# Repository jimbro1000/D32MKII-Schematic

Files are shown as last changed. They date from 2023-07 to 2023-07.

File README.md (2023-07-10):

# Dragon 32 MKII Schematic

Captured in KiCad by Stewart Orchard 2015-2019

Original design by Dragon Data Ltd circa 1982

PCB Reproduction by Julian Brown 2023

## Why?

The published Dragon schematics do not appear to include MKII versions, which can be a problem for repairs as there are differences in the memory configuration, the video circuit and logic gate pin numbers. I captured this information around the year 1998 with reference to the existing ISS2 schematics, a multimeter and a real MKII ISS6 main board, and have finally got round to recording it as a KiCad project.

## Disclaimer

Much as I would like to think that I've got this 100% correct, there is always the chance that there are mistakes and omissions. I would recommend checking that the information is accurate before using this schematic for anything potentially expensive.

## PCB Design

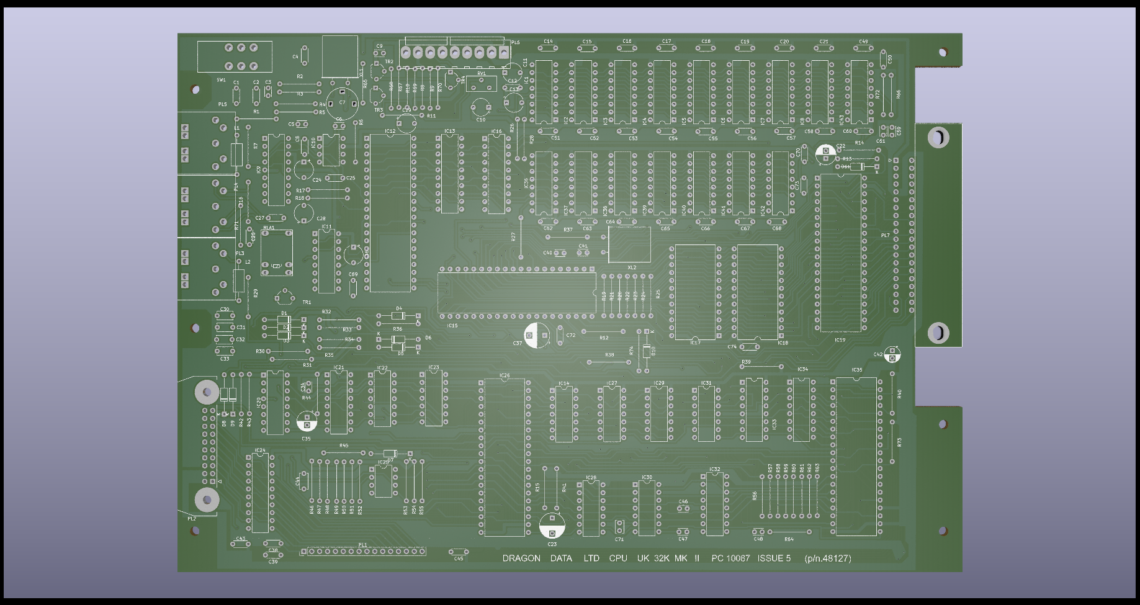
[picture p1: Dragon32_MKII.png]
render of pcb


The PCB layout has been added to further assist with rapid identification of components and 
interconnections between components

This is not an attempt to reverse-engineer the board for production and no support will be given

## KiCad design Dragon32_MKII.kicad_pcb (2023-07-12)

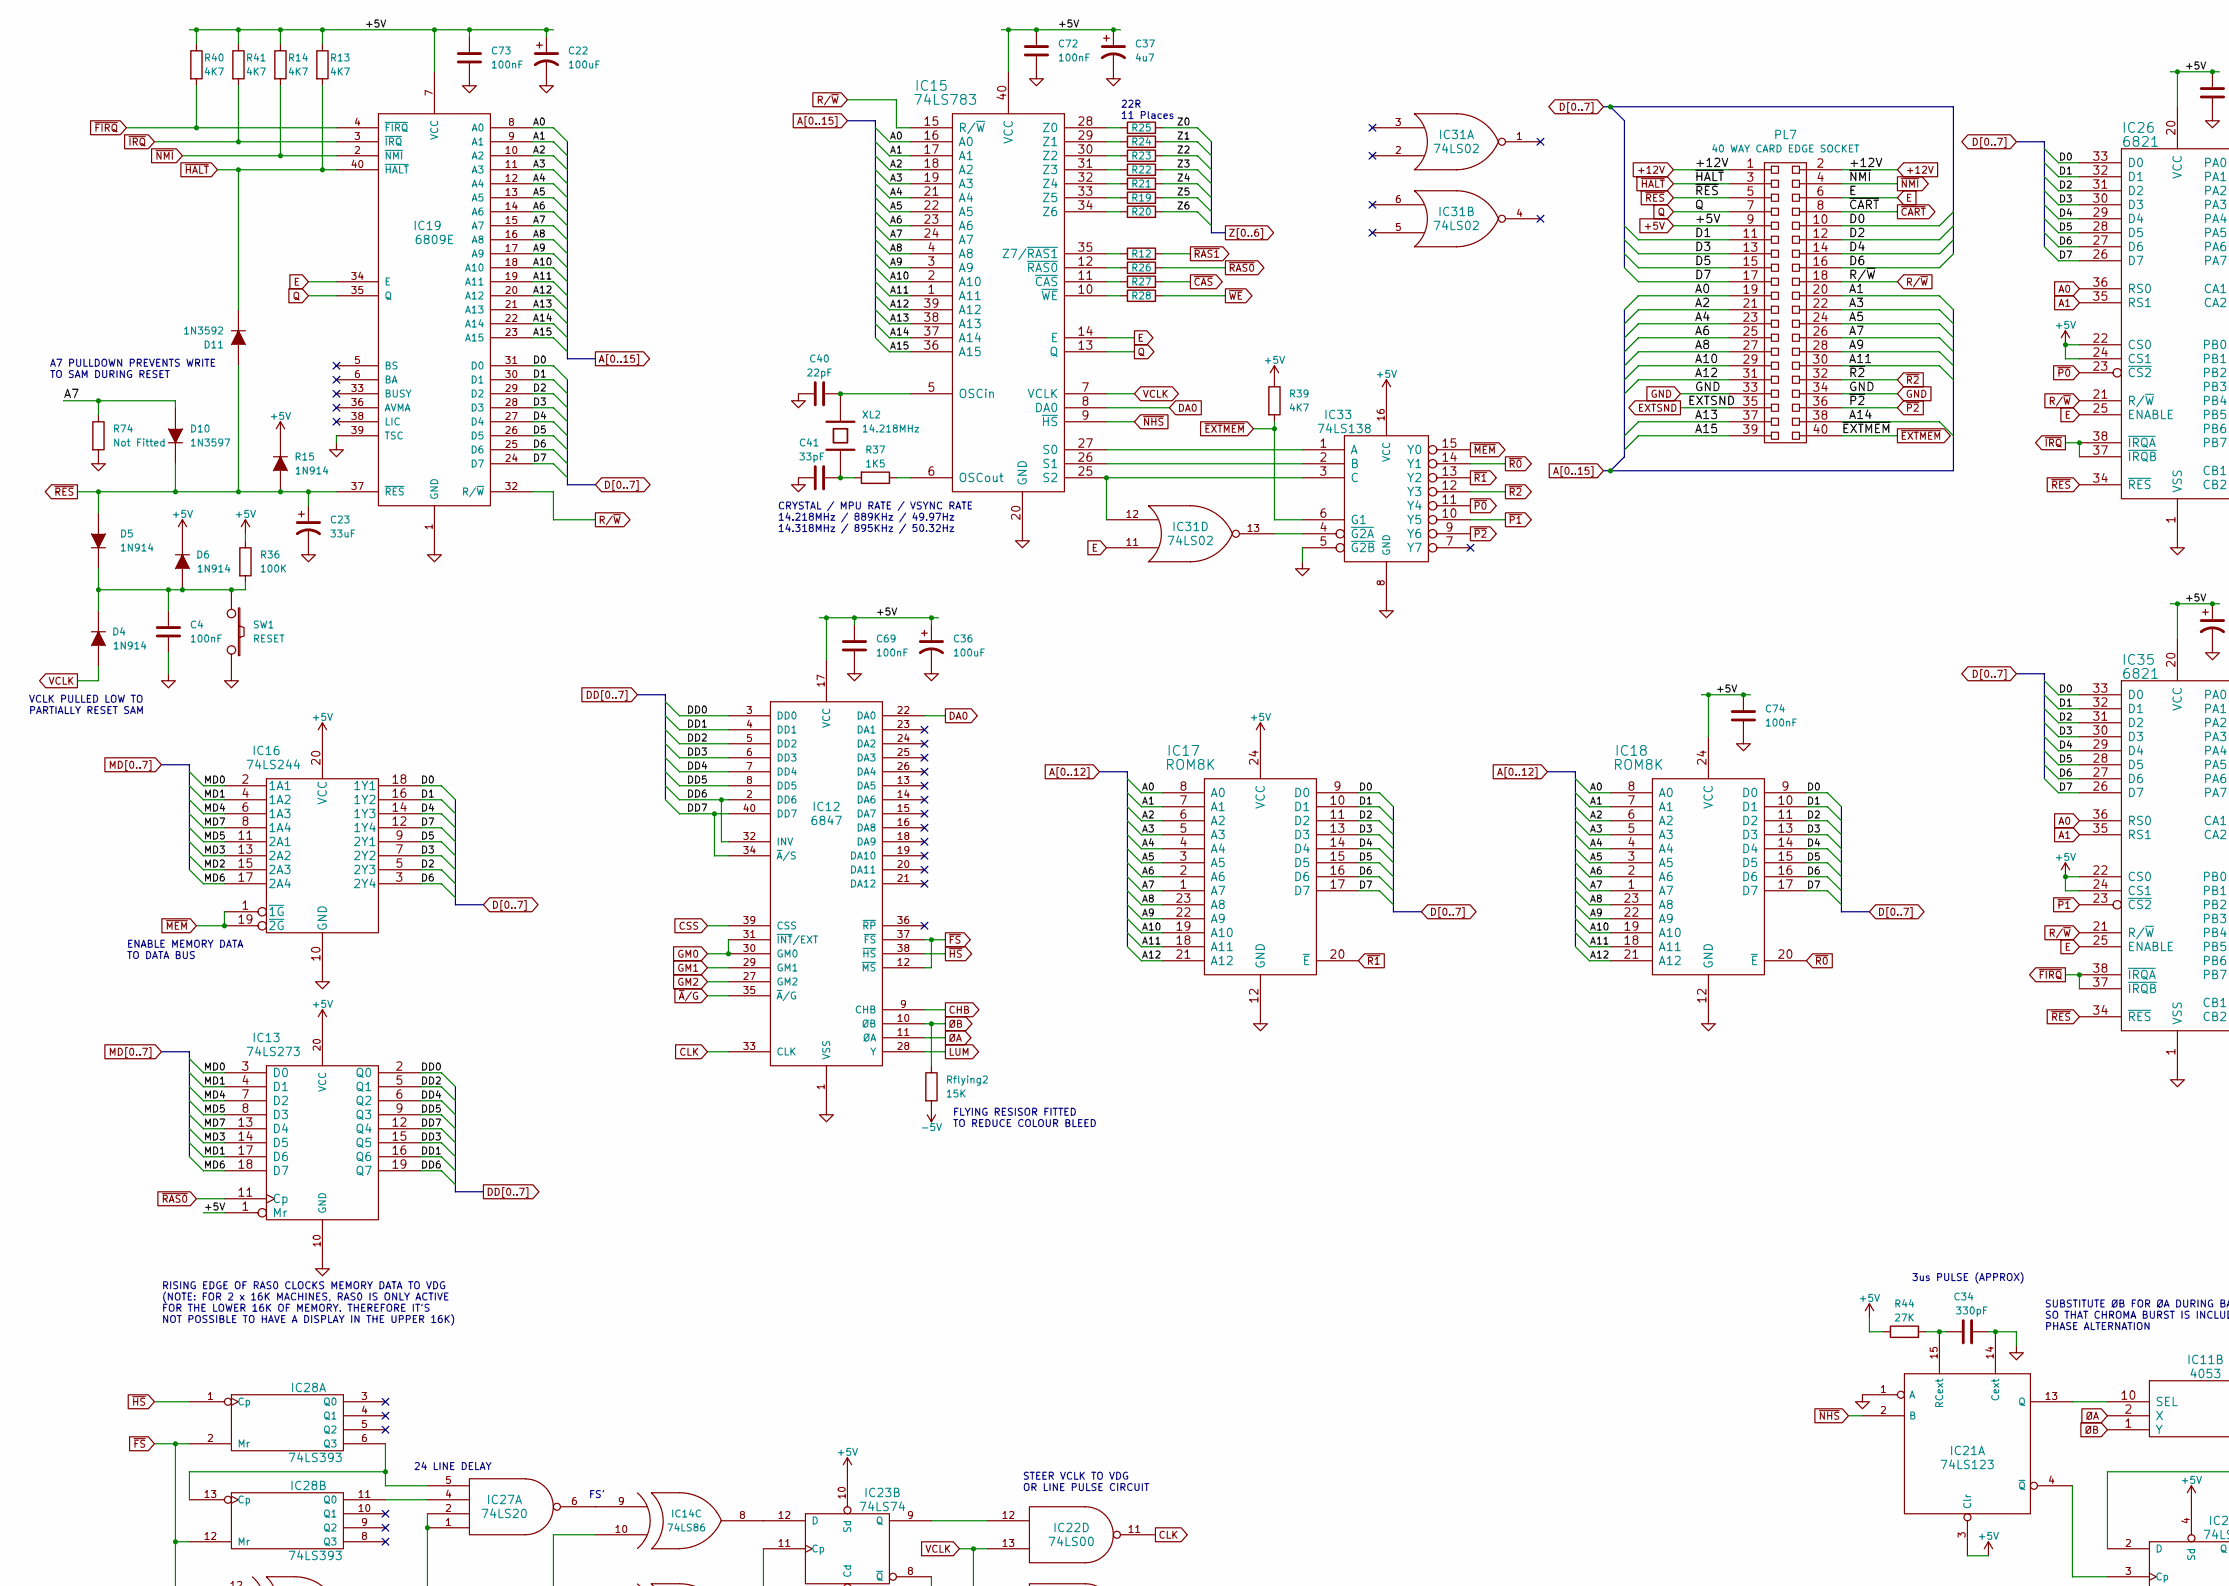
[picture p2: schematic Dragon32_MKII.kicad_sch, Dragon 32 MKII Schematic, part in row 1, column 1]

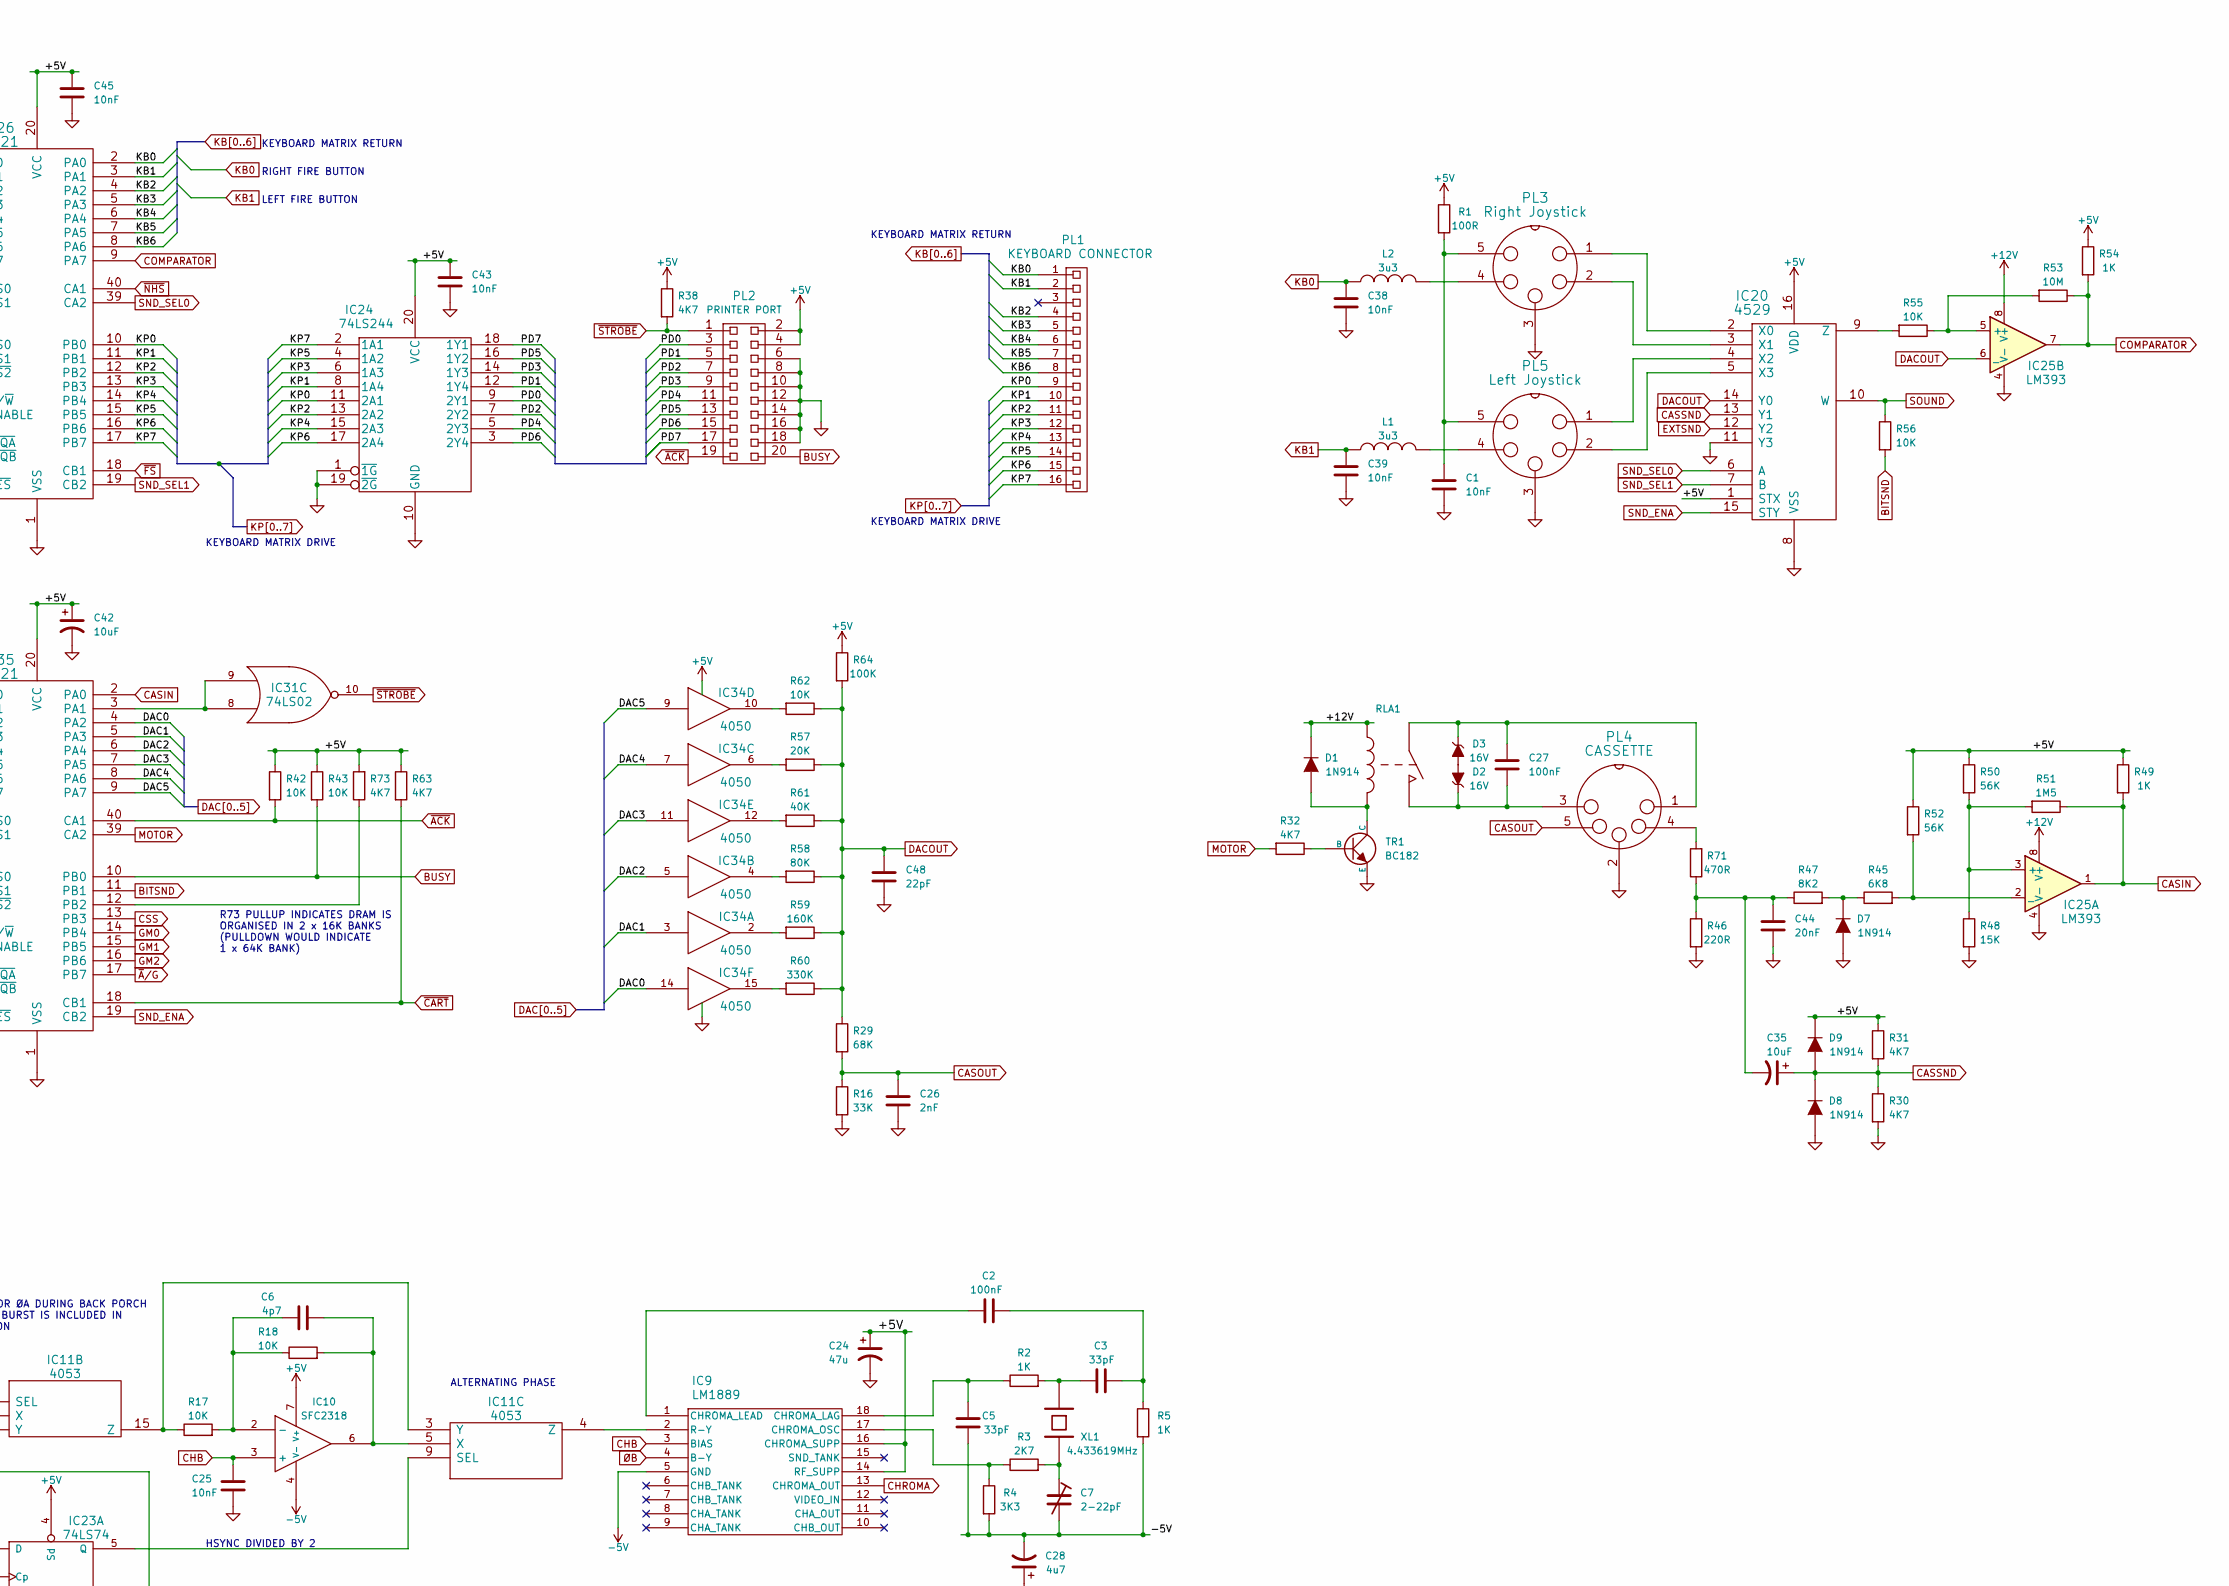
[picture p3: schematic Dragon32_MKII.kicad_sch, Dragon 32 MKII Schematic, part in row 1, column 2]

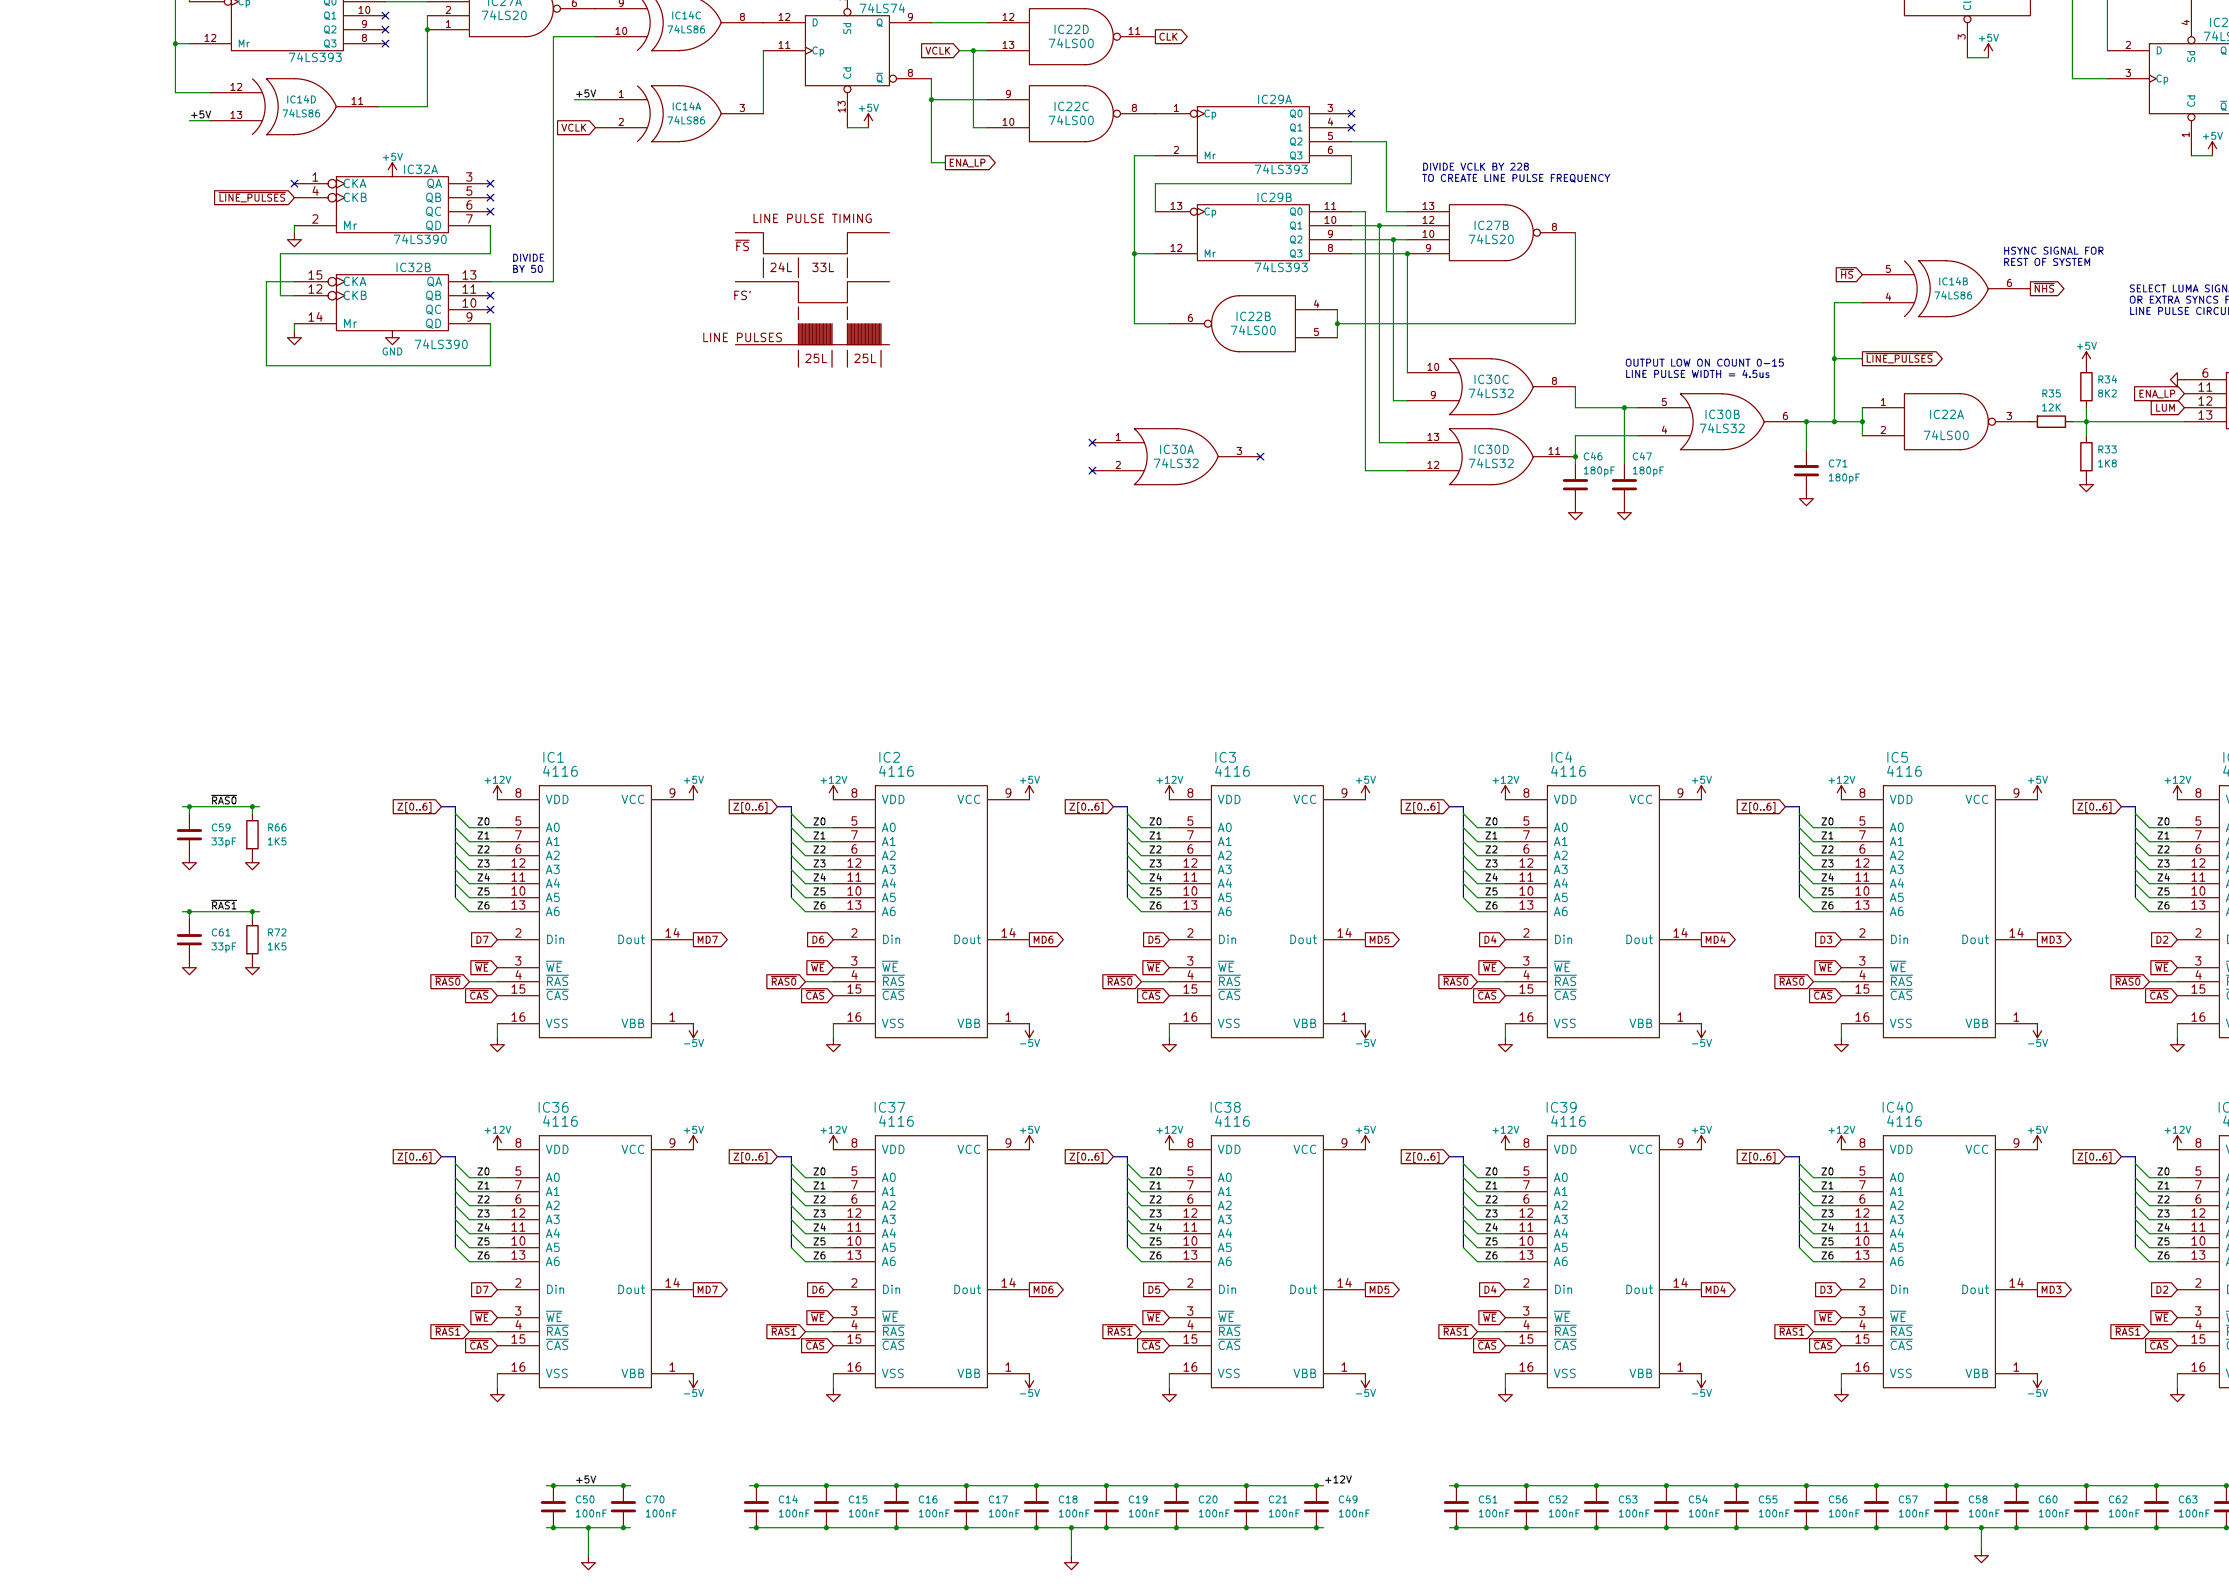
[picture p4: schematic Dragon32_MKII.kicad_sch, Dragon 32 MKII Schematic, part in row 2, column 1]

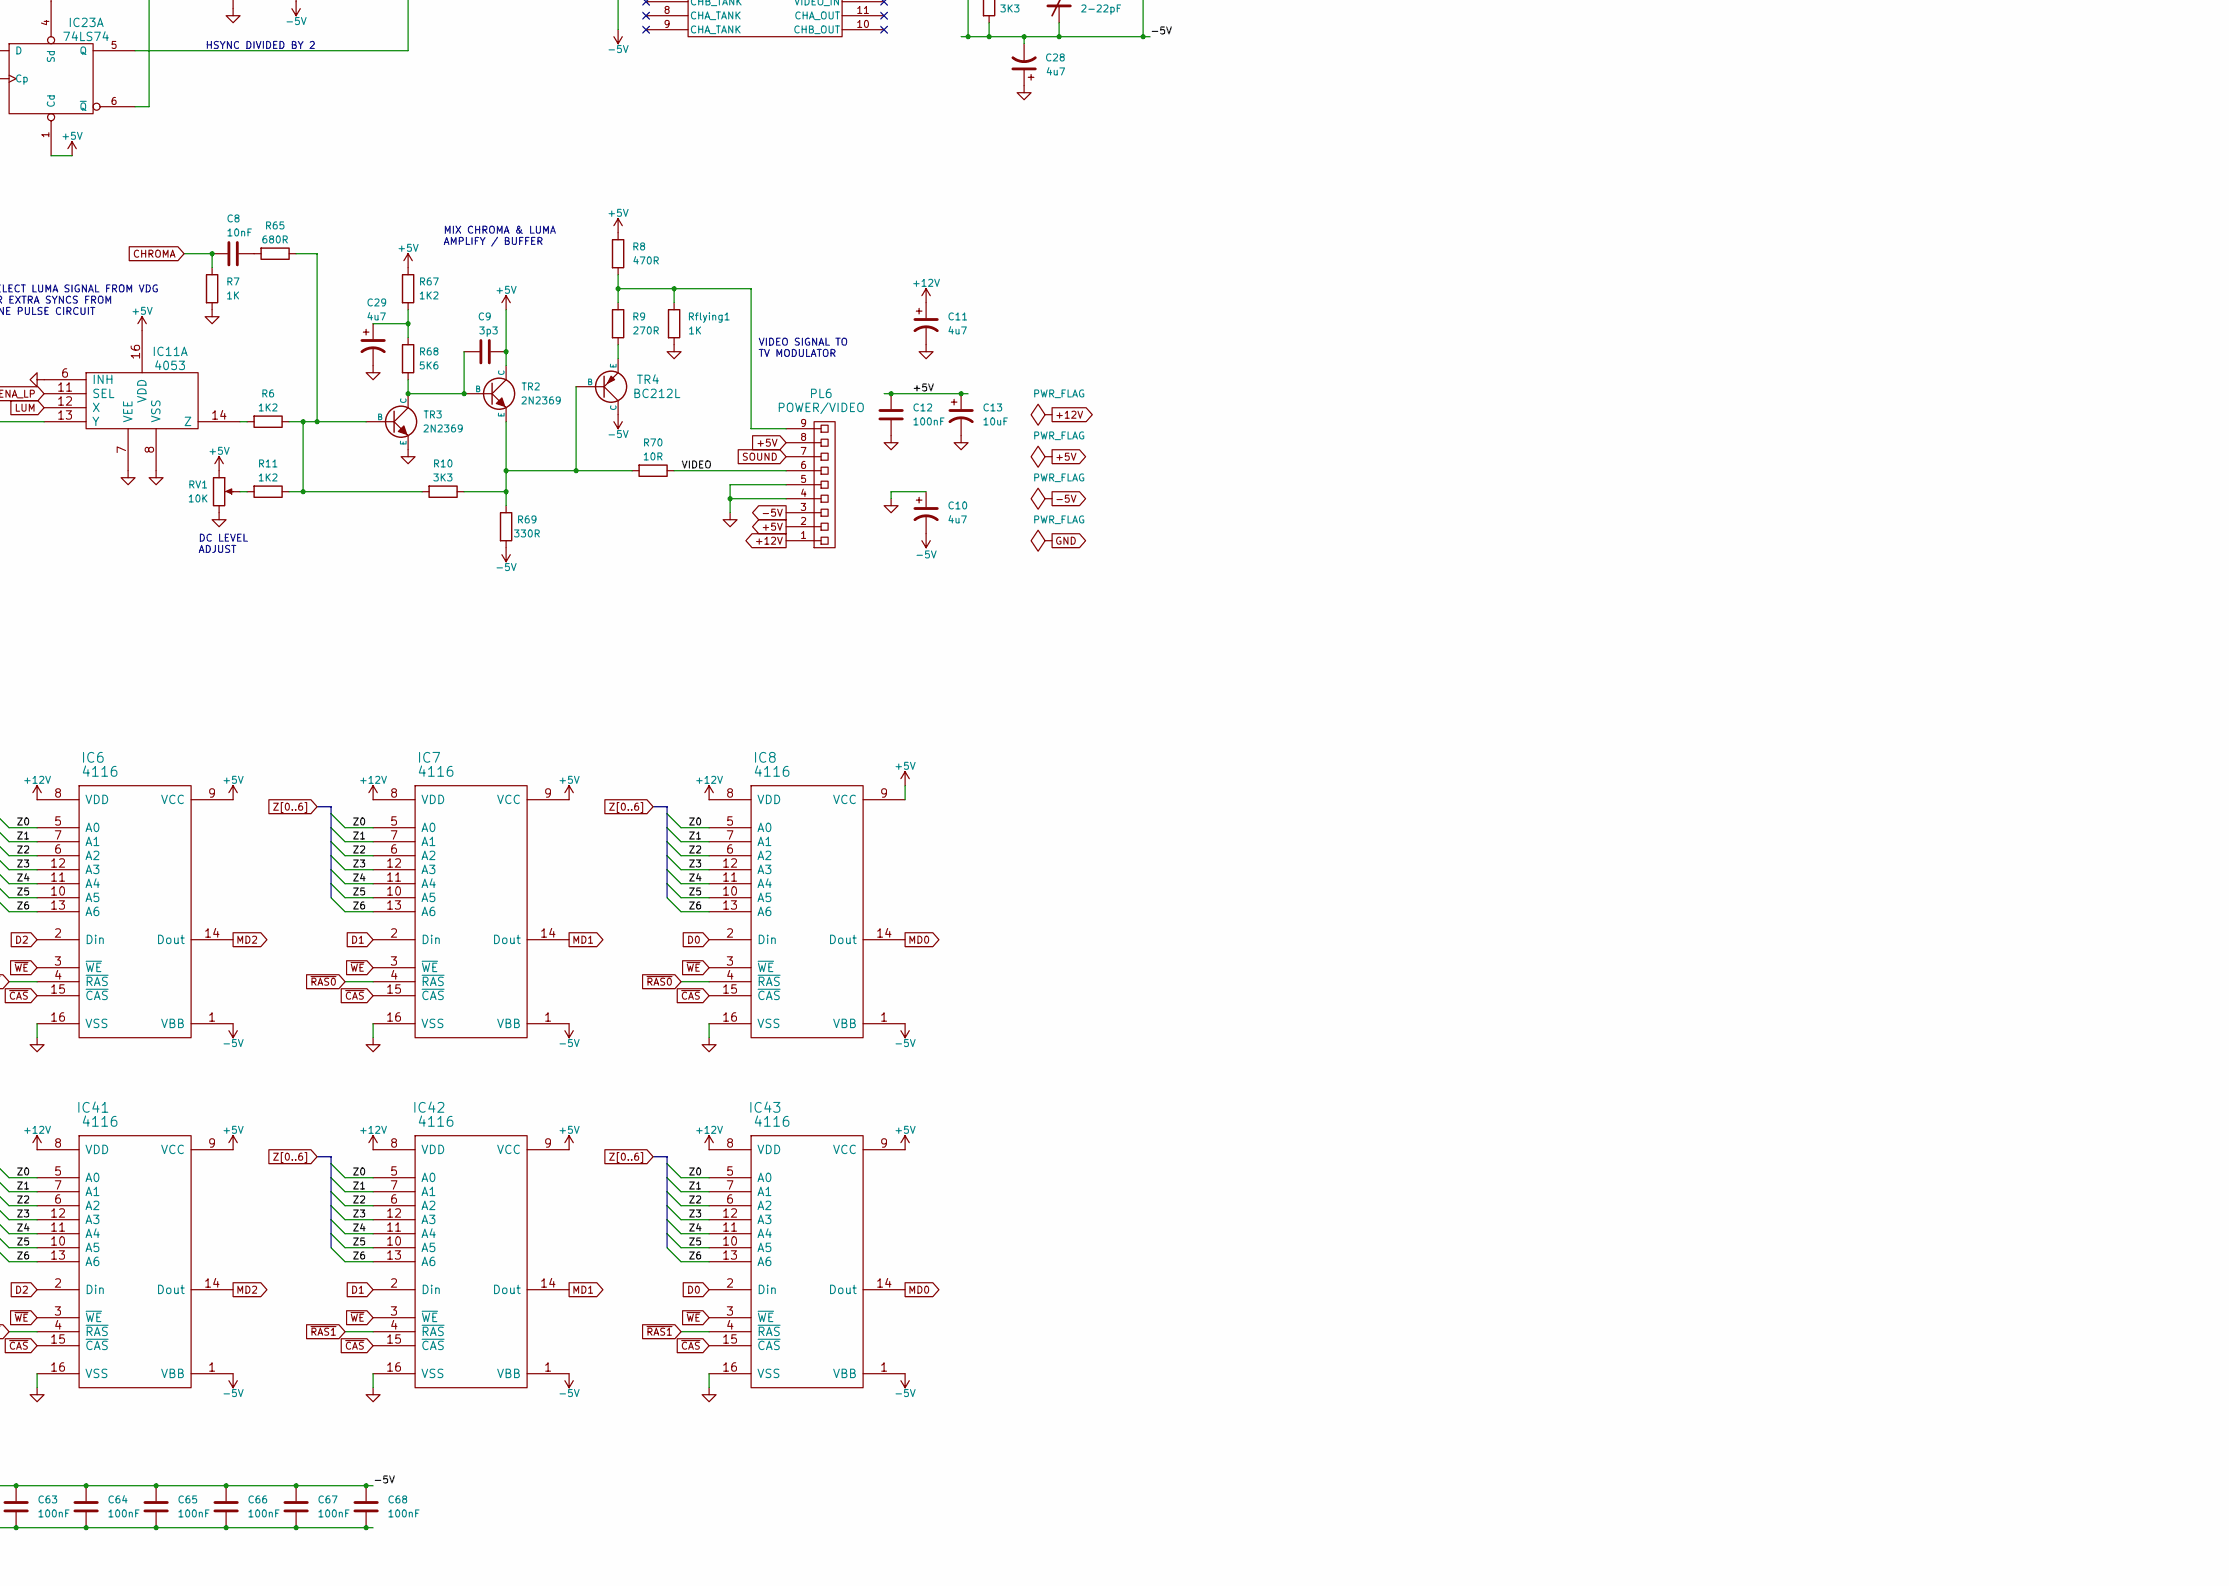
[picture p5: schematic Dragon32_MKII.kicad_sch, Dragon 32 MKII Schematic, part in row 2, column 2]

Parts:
C1, C8, C25, C38, C39, C43, C45: 10nF; C_Disc_D4.3mm_W1.9mm_P5.00mm
C2, C4, C12, C14, C15, C16, C17, C18, C19, C20, C21, C27, C49, C50, C51, C52, C53, C54, C55, C56, C57, C58, C60, C62, C63, C64, C65, C66, C67, C68, C69, C70, C72, C73, C74: 100nF; C_Disc_D4.3mm_W1.9mm_P5.00mm
C3, C5, C41, C59, C61: 33pF; C_Disc_D3.0mm_W2.0mm_P2.50mm
C6: 4p7; C_Disc_D3.0mm_W2.0mm_P2.50mm
C7: 2-22pF; Trimmer-7.5mm
C9: 3p3; C_Disc_D3.0mm_W2.0mm_P2.50mm
C10, C11, C28, C29, C37: 4u7; CP_Radial_D5.0mm_P2.50mm
C13, C35, C42: 10uF; CP_Radial_D5.0mm_P2.50mm
C22, C36: 100uF; CP_Radial_D6.3mm_P2.50mm
C23: 33uF; CP_Radial_D5.0mm_P2.50mm
C24: 47u; CP_Radial_D5.0mm_P2.50mm
C26: 2nF; C_Disc_D3.0mm_W2.0mm_P2.50mm
C34: 330pF; C_Disc_D3.0mm_W2.0mm_P2.50mm
C40, C48: 22pF; C_Disc_D3.0mm_W2.0mm_P2.50mm
C44: 20nF; C_Disc_D5.0mm_W2.5mm_P5.00mm
C46, C47: 180pF; C_Disc_D3.0mm_W2.0mm_P2.50mm
C71: 180pF; C_Disc_D3.8mm_W2.6mm_P2.50mm
D1, D4, D5, D6, D7, D8, D9: 1N914; D_DO-35_SOD27_P7.62mm_Horizontal
D2, D3: 16V; D_DO-35_SOD27_P7.62mm_Horizontal
D10: 1N3597; D_DO-35_SOD27_P7.62mm_Horizontal
D11: 1N3592; D_DO-35_SOD27_P12.70mm_Horizontal
IC1, IC2, IC3, IC4, IC5, IC6, IC7, IC8, IC36, IC37, IC38, IC39, IC40, IC41, IC42, IC43: 4116; DIP-16_W7.62mm
IC9: LM1889; DIP-18_W7.62mm
IC10: SFC2318; DIP-8_W7.62mm
IC11: 4053; DIP-16_W7.62mm
IC12: 6847; DIP-40_W15.24mm
IC13: 74LS273; DIP-20_W7.62mm
IC14: 74LS86; DIP-14_W7.62mm
IC15: 74LS783; DIP-40_W15.24mm
IC16, IC24: 74LS244; DIP-20_W7.62mm
IC17, IC18: ROM8K; DIP-24_W15.24mm
IC19: 6809E; DIP-40_W15.24mm
IC20: 4529; DIP-16_W7.62mm
IC21: 74LS123; DIP-16_W7.62mm
IC22: 74LS00; DIP-14_W7.62mm
IC23: 74LS74; DIP-14_W7.62mm
IC25: LM393; DIP-8_W7.62mm
IC26, IC35: 6821; DIP-40_W15.24mm
IC27: 74LS20; DIP-14_W7.62mm
IC28, IC29: 74LS393; DIP-14_W7.62mm
IC30: 74LS32; DIP-14_W7.62mm
IC31: 74LS02; DIP-14_W7.62mm
IC32: 74LS390; DIP-16_W7.62mm
IC33: 74LS138; DIP-16_W7.62mm
IC34: 4050; DIP-16_W7.62mm
L1, L2: 3u3; L_Axial_L7.0mm_D3.3mm_P10.16mm_Horizontal_Fastron_MICC
PL1: KEYBOARD CONNECTOR; PinHeader_1x16_P2.54mm_Vertical
PL2: PRINTER PORT; IDC-Header_2x10-1MP_P2.54mm_Latch_Horizontal
PL3: Right Joystick; DIN-5_DELTRON_671-0501_45deg_Horizontal
PL4: CASSETTE; DIN-5_DELTRON_671-0501_45deg_Horizontal
PL5: Left Joystick; DIN-5_DELTRON_671-0501_45deg_Horizontal
PL6: POWER/VIDEO; Molex_KK-396_A-41791-0009_1x09_P3.96mm_Vertical
PL7: 40 WAY CARD EDGE SOCKET; Edge_2x20_P2.54mm_OvalMP
R1: 100R; R_Axial_DIN0207_L6.3mm_D2.5mm_P12.7mm_Horizontal
R2, R5, R7, R49, R54: 1K; R_Axial_DIN0207_L6.3mm_D2.5mm_P12.7mm_Horizontal
R3: 2K7; R_Axial_DIN0207_L6.3mm_D2.5mm_P12.7mm_Horizontal
R4: 3K3; R_Axial_DIN0207_L6.3mm_D2.5mm_P12.7mm_Horizontal
R6, R11: 1K2; R_Axial_DIN0207_L6.3mm_D2.5mm_P12.7mm_Horizontal
R8: 470R; R_Axial_DIN0207_L6.3mm_D2.5mm_P10.16mm_Horizontal
R9: 270R; R_Axial_DIN0207_L6.3mm_D2.5mm_P10.16mm_Horizontal
R10: 3K3; R_Axial_DIN0207_L6.3mm_D2.5mm_P10.16mm_Horizontal
R12, R19, R20, R21, R22, R23, R24, R25, R26, R27, R28: 22R; R_Axial_DIN0207_L6.3mm_D2.5mm_P12.7mm_Horizontal
R13, R14, R30, R31, R32, R38, R39, R40, R41, R63, R73: 4K7; R_Axial_DIN0207_L6.3mm_D2.5mm_P12.7mm_Horizontal
R15: 1N914; R_Axial_DIN0207_L6.3mm_D2.5mm_P12.7mm_Horizontal
R16: 33K; R_Axial_DIN0207_L6.3mm_D2.5mm_P12.7mm_Horizontal
R17, R18, R42, R43, R55, R56, R62: 10K; R_Axial_DIN0207_L6.3mm_D2.5mm_P12.7mm_Horizontal
R29: 68K; R_Axial_DIN0207_L6.3mm_D2.5mm_P12.7mm_Horizontal
R33: 1K8; R_Axial_DIN0207_L6.3mm_D2.5mm_P12.7mm_Horizontal
R34, R47: 8K2; R_Axial_DIN0207_L6.3mm_D2.5mm_P12.7mm_Horizontal
R35: 12K; R_Axial_DIN0207_L6.3mm_D2.5mm_P12.7mm_Horizontal
R36, R64: 100K; R_Axial_DIN0207_L6.3mm_D2.5mm_P12.7mm_Horizontal
R37, R66, R72: 1K5; R_Axial_DIN0207_L6.3mm_D2.5mm_P12.7mm_Horizontal
R44: 27K; R_Axial_DIN0207_L6.3mm_D2.5mm_P12.7mm_Horizontal
R45: 6K8; R_Axial_DIN0207_L6.3mm_D2.5mm_P12.7mm_Horizontal
R46: 220R; R_Axial_DIN0207_L6.3mm_D2.5mm_P12.7mm_Horizontal
R48: 15K; R_Axial_DIN0207_L6.3mm_D2.5mm_P12.7mm_Horizontal
R50, R52: 56K; R_Axial_DIN0207_L6.3mm_D2.5mm_P12.7mm_Horizontal
R51: 1M5; R_Axial_DIN0207_L6.3mm_D2.5mm_P12.7mm_Horizontal
R53: 10M; R_Axial_DIN0207_L6.3mm_D2.5mm_P12.7mm_Horizontal
R57: 20K; R_Axial_DIN0207_L6.3mm_D2.5mm_P12.7mm_Horizontal
R58: 80K; R_Axial_DIN0207_L6.3mm_D2.5mm_P12.7mm_Horizontal
R59: 160K; R_Axial_DIN0207_L6.3mm_D2.5mm_P12.7mm_Horizontal
R60: 330K; R_Axial_DIN0207_L6.3mm_D2.5mm_P12.7mm_Horizontal
R61: 40K; R_Axial_DIN0207_L6.3mm_D2.5mm_P12.7mm_Horizontal
R65: 680R; R_Axial_DIN0207_L6.3mm_D2.5mm_P12.7mm_Horizontal
R67: 1K2; R_Axial_DIN0207_L6.3mm_D2.5mm_P10.16mm_Horizontal
R68: 5K6; R_Axial_DIN0207_L6.3mm_D2.5mm_P10.16mm_Horizontal
R69: 330R; R_Axial_DIN0207_L6.3mm_D2.5mm_P10.16mm_Horizontal
R70: 10R; R_Axial_DIN0207_L6.3mm_D2.5mm_P10.16mm_Horizontal
R71: 470R; R_Axial_DIN0207_L6.3mm_D2.5mm_P12.7mm_Horizontal
R74: Not Fitted
RLA1: RELAY; OJS HM 10A Relay
RV1: 10K; Potentiometer_Bourns_3386X_Horizontal
Rflying1: 1K
Rflying2: 15K
SW1: RESET; Button_AlpsAlpine_SPUN190900
TR1: BC182; TO-92L_Inline_Wide
TR2, TR3: 2N2369; TO-92L_Inline_Wide
TR4: BC212L; TO-92L_Inline_Wide
U1: LINE_PULSE_DIAGRAM
XL1: 4.433619MHz; Crystal_HC49-U_Horizontal
XL2: 14.218MHz; Crystal_HC49-U_Horizontal

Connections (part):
+5V: C9.2, C12.1, C13.1, C22.1, C24.1, C36.1, C37.1, C42.1, C43.1, C45.1, C50.1, C69.1, C70.1, C72.1, C73.1, C74.1, D6.2 (K), D9.2 (K), IC1.9 (VCC), IC2.9 (VCC), IC3.9 (VCC), IC4.9 (VCC), IC5.9 (VCC), IC6.9 (VCC), IC7.9 (VCC), IC8.9 (VCC), IC9.14 (RF_SUPP), IC9.16 (CHROMA_SUPP), IC10.7 (V+), IC11.16 (VDD), IC12.17 (VCC), IC13.1 (Mr), IC13.20 (VCC), IC14.1 (IN1), IC14.13 (IN2), IC14.14 (VCC), IC15.40 (VCC), IC16.20 (VCC), IC17.24 (VCC), IC18.24 (VCC), IC19.7 (VCC), IC20.1 (STX), IC20.16 (VDD), IC21.3 (Clr), IC21.16 (VCC), IC22.14 (VCC), IC23.1 (Cd), IC23.4 (Sd), IC23.10 (Sd), IC23.13 (Cd), IC23.14 (VCC), IC24.20 (VCC), IC26.20 (VCC), IC26.22 (CS0), IC26.24 (CS1), IC27.14 (VCC), IC28.14 (VCC), IC29.14 (VCC), IC30.14 (VCC), IC31.14 (VCC), IC32.16 (VCC), IC33.16 (VCC), IC34.1 (VCC), IC35.20 (VCC), IC35.22 (CS0), IC35.24 (CS1), IC36.9 (VCC), IC37.9 (VCC), IC38.9 (VCC), IC39.9 (VCC), IC40.9 (VCC), IC41.9 (VCC), IC42.9 (VCC), IC43.9 (VCC), PL2.2, PL2.4, PL6.2, PL6.8, PL7.9, R1.1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
+12V: C11.1, C14.1, C15.1, C16.1, C17.1, C18.1, C19.1, C20.1, C21.1, C49.1, D1.2 (K), IC1.8 (VDD), IC2.8 (VDD), IC3.8 (VDD), IC4.8 (VDD), IC5.8 (VDD), IC6.8 (VDD), IC7.8 (VDD), IC8.8 (VDD), IC25.8 (V+), IC36.8 (VDD), IC37.8 (VDD), IC38.8 (VDD), IC39.8 (VDD), IC40.8 (VDD), IC41.8 (VDD), IC42.8 (VDD), IC43.8 (VDD), PL6.1, PL7.1, PL7.2, RLA1.1
-5V: C5.1, C7.2, C10.2, C28.2, C51.1, C52.1, C53.1, C54.1, C55.1, C56.1, C57.1, C58.1, C60.1, C62.1, C63.1, C64.1, C65.1, C66.1, C67.1, C68.1, IC1.1 (VBB), IC2.1 (VBB), IC3.1 (VBB), IC4.1 (VBB), IC5.1 (VBB), IC6.1 (VBB), IC7.1 (VBB), IC8.1 (VBB), IC9.5 (GND), IC10.4 (V-), IC36.1 (VBB), IC37.1 (VBB), IC38.1 (VBB), IC39.1 (VBB), IC40.1 (VBB), IC41.1 (VBB), IC42.1 (VBB), IC43.1 (VBB), PL6.3, R4.2, R5.2, R69.2, Rflying2.2, TR4.3 (C)
/PD0: IC24.9 (2Y1), PL2.3
/PD1: IC24.12 (1Y4), PL2.5
/PD2: IC24.7 (2Y2), PL2.7
/PD3: IC24.14 (1Y3), PL2.9
/PD4: IC24.5 (2Y3), PL2.11
/PD5: IC24.16 (1Y2), PL2.13
/PD6: IC24.3 (2Y4), PL2.15
/PD7: IC24.18 (1Y1), PL2.17
/VIDEO: PL6.6, R70.1
A0: IC15.16 (A0), IC17.8 (A0), IC18.8 (A0), IC19.8 (A0), IC26.36 (RS0), IC35.36 (RS0), PL7.19
A1: IC15.17 (A1), IC17.7 (A1), IC18.7 (A1), IC19.9 (A1), IC26.35 (RS1), IC35.35 (RS1), PL7.20
A2: IC15.18 (A2), IC17.6 (A2), IC18.6 (A2), IC19.10 (A2), PL7.21
A3: IC15.19 (A3), IC17.5 (A3), IC18.5 (A3), IC19.11 (A3), PL7.22
A4: IC15.21 (A4), IC17.4 (A4), IC18.4 (A4), IC19.12 (A4), PL7.23
A5: IC15.22 (A5), IC17.3 (A5), IC18.3 (A5), IC19.13 (A5), PL7.24
A6: IC15.23 (A6), IC17.2 (A6), IC18.2 (A6), IC19.14 (A6), PL7.25
A7: D10.1 (A), IC15.24 (A7), IC17.1 (A7), IC18.1 (A7), IC19.15 (A7), PL7.26, R74.1
A8: IC15.4 (A8), IC17.23 (A8), IC18.23 (A8), IC19.16 (A8), PL7.27
A9: IC15.3 (A9), IC17.22 (A9), IC18.22 (A9), IC19.17 (A9), PL7.28
A10: IC15.2 (A10), IC17.19 (A10), IC18.19 (A10), IC19.18 (A10), PL7.29
A11: IC15.1 (A11), IC17.18 (A11), IC18.18 (A11), IC19.19 (A11), PL7.30
A12: IC15.39 (A12), IC17.21 (A12), IC18.21 (A12), IC19.20 (A12), PL7.31
A13: IC15.38 (A13), IC19.21 (A13), PL7.37
A14: IC15.37 (A14), IC19.22 (A14), PL7.38
A15: IC15.36 (A15), IC19.23 (A15), PL7.39
BITSND: IC35.11 (PB1), R56.2
BUSY: IC35.10 (PB0), PL2.20, R43.2
CASIN: IC25.1, IC35.2 (PA0), R49.2, R51.1
CASOUT: C26.1, PL4.5, R16.1, R29.2
CASSND: C35.1, D8.2 (K), D9.1 (A), IC20.13 (Y1), R30.1, R31.2
CHB: C25.1, IC9.3 (BIAS), IC10.3 (+), IC12.9 (CHB)
CHROMA: C8.2, IC9.13 (CHROMA_OUT), R7.1
CLK: IC12.33 (CLK), IC22.11
COMPARATOR: IC25.7, IC26.9 (PA7), R53.1, R54.2
CSS: IC12.39 (CSS), IC35.13 (PB3)
D0: IC8.2 (Din), IC16.18 (1Y1), IC17.9 (D0), IC18.9 (D0), IC19.31 (D0), IC26.33 (D0), IC35.33 (D0), IC43.2 (Din), PL7.10
D1: IC7.2 (Din), IC16.16 (1Y2), IC17.10 (D1), IC18.10 (D1), IC19.30 (D1), IC26.32 (D1), IC35.32 (D1), IC42.2 (Din), PL7.11
D2: IC6.2 (Din), IC16.5 (2Y3), IC17.11 (D2), IC18.11 (D2), IC19.29 (D2), IC26.31 (D2), IC35.31 (D2), IC41.2 (Din), PL7.12
D3: IC5.2 (Din), IC16.7 (2Y2), IC17.13 (D3), IC18.13 (D3), IC19.28 (D3), IC26.30 (D3), IC35.30 (D3), IC40.2 (Din), PL7.13
D4: IC4.2 (Din), IC16.14 (1Y3), IC17.14 (D4), IC18.14 (D4), IC19.27 (D4), IC26.29 (D4), IC35.29 (D4), IC39.2 (Din), PL7.14
D5: IC3.2 (Din), IC16.9 (2Y1), IC17.15 (D5), IC18.15 (D5), IC19.26 (D5), IC26.28 (D5), IC35.28 (D5), IC38.2 (Din), PL7.15
D6: IC2.2 (Din), IC16.3 (2Y4), IC17.16 (D6), IC18.16 (D6), IC19.25 (D6), IC26.27 (D6), IC35.27 (D6), IC37.2 (Din), PL7.16
D7: IC1.2 (Din), IC16.12 (1Y4), IC17.17 (D7), IC18.17 (D7), IC19.24 (D7), IC26.26 (D7), IC35.26 (D7), IC36.2 (Din), PL7.17
DA0: IC12.22 (DA0), IC15.8 (DA0)
DAC0: IC34.14, IC35.4 (PA2)
DAC1: IC34.3, IC35.5 (PA3)
DAC2: IC34.5, IC35.6 (PA4)
DAC3: IC34.11, IC35.7 (PA5)
DAC4: IC34.7, IC35.8 (PA6)
DAC5: IC34.9, IC35.9 (PA7)
DACOUT: C48.1, IC20.14 (Y0), IC25.6 (_), R29.1, R57.1, R58.1, R59.1, R60.1, R61.1, R62.1, R64.2
DD0: IC12.3 (DD0), IC13.2 (Q0)
DD1: IC12.4 (DD1), IC13.16 (Q6)
DD2: IC12.5 (DD2), IC13.5 (Q1)
DD3: IC12.6 (DD3), IC13.15 (Q5)
DD4: IC12.7 (DD4), IC13.6 (Q2)
DD5: IC12.8 (DD5), IC13.9 (Q3)
DD6: IC12.2 (DD6), IC12.32 (INV), IC13.19 (Q7)
DD7: IC12.34 (~A/S), IC12.40 (DD7), IC13.12 (Q4)
E: IC15.14 (E), IC19.34 (E), IC26.25 (ENABLE), IC31.11, IC35.25 (ENABLE), PL7.6
ENA_LP: IC11.11 (SEL), IC22.9, IC23.8 (~Q)
EXTSND: IC20.12 (Y2), PL7.35
GM0: IC12.30 (GM0), IC12.31 (~INT/EXT), IC35.14 (PB4)
GM1: IC12.29 (GM1), IC35.15 (PB5)
GM2: IC12.27 (GM2), IC35.16 (PB6)
GND: C1.2, C4.2, C10.1, C11.2, C12.2, C13.2, C14.2, C15.2, C16.2, C17.2, C18.2, C19.2, C20.2, C21.2, C22.2, C23.2, C24.2, C25.2, C26.2, C28.1, C29.2, C34.2, C36.2, C37.2, C38.2, C39.2, C40.2, C41.2, C42.2, C43.2, C44.2, C45.2, C46.2, C47.2, C48.2, C49.2, C50.2, C51.2, C52.2, C53.2, C54.2, C55.2, C56.2, C57.2, C58.2, C59.2, C60.2, C61.2, C62.2, C63.2, C64.2, C65.2, C66.2, C67.2, C68.2, C69.2, C70.2, C71.2, C72.2, C73.2, C74.2, D7.1 (A), D8.1 (A), IC1.16 (VSS), IC2.16 (VSS), IC3.16 (VSS), IC4.16 (VSS), IC5.16 (VSS), IC6.16 (VSS), IC7.16 (VSS), IC8.16 (VSS), IC11.6 (INH), IC11.7 (VEE), IC11.8 (VSS), IC12.1 (VSS), IC13.10 (GND), IC14.7 (GND), IC15.20 (GND), IC16.10 (GND), IC17.12 (GND)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
KB0: C38.1, IC26.2 (PA0), L2.1, PL1.1
KB1: C39.1, IC26.3 (PA1), L1.1, PL1.2
KB2: IC26.4 (PA2), PL1.4
KB3: IC26.5 (PA3), PL1.5
KB4: IC26.6 (PA4), PL1.6
KB5: IC26.7 (PA5), PL1.7
KB6: IC26.8 (PA6), PL1.8
KP0: IC24.11 (2A1), IC26.10 (PB0), PL1.9
KP1: IC24.8 (1A4), IC26.11 (PB1), PL1.10
KP2: IC24.13 (2A2), IC26.12 (PB2), PL1.11
KP3: IC24.6 (1A3), IC26.13 (PB3), PL1.12
KP4: IC24.15 (2A3), IC26.14 (PB4), PL1.13
KP5: IC24.4 (1A2), IC26.15 (PB5), PL1.14
KP6: IC24.17 (2A4), IC26.16 (PB6), PL1.15
KP7: IC24.2 (1A1), IC26.17 (PB7), PL1.16
LUM: IC11.12 (X), IC12.28 (Y)
MD0: IC8.14 (Dout), IC13.3 (D0), IC16.2 (1A1), IC43.14 (Dout)
MD1: IC7.14 (Dout), IC13.4 (D1), IC13.17 (D6), IC16.4 (1A2), IC42.14 (Dout)
MD2: IC6.14 (Dout), IC16.15 (2A3), IC41.14 (Dout)
MD3: IC5.14 (Dout), IC13.14 (D5), IC16.13 (2A2), IC40.14 (Dout)
MD4: IC4.14 (Dout), IC13.7 (D2), IC16.6 (1A3), IC39.14 (Dout)
MD5: IC3.14 (Dout), IC13.8 (D3), IC16.11 (2A1), IC38.14 (Dout)
MD6: IC2.14 (Dout), IC13.18 (D7), IC16.17 (2A4), IC37.14 (Dout)
MD7: IC1.14 (Dout), IC13.13 (D4), IC16.8 (1A4), IC36.14 (Dout)
MOTOR: IC35.39 (CA2), R32.2
unnamed: C1.1, PL3.5, PL5.5, R1.2
unnamed: C2.2, C3.2, R5.1
unnamed: C3.1, R2.2, XL1.1
unnamed: C7.1, R3.2, XL1.2
unnamed: C8.1, R65.2
unnamed: C29.1, R67.2, R68.1
unnamed: C35.2, C44.1, R46.1, R47.1, R71.1
unnamed: C41.1, R37.2, XL2.2
unnamed: C46.1, IC30.4, IC30.11
unnamed: C47.1, IC30.5, IC30.8
unnamed: D1.1 (A), RLA1.2, TR1.1 (C)
unnamed: D2.1 (A), D3.1 (A)
unnamed: C27.2, D2.2 (K), PL4.3, RLA1.4
unnamed: C27.1, D3.2 (K), PL4.1, RLA1.3
unnamed: C4.1, D4.2 (K), D5.2 (K), D6.1 (A), R36.2, SW1.2
unnamed: D7.2 (K), R45.1, R47.2
unnamed: C5.2, IC9.18 (CHROMA_LAG), R2.1
unnamed: C2.1, IC9.1 (CHROMA_LEAD)
unnamed: IC9.17 (CHROMA_OSC), R3.1, R4.1
unnamed: C6.1, IC10.2 (-), R17.2, R18.1
unnamed: IC11.13 (Y), R33.1, R34.2, R35.1
unnamed: IC11.14 (Z), R6.2
unnamed: IC11.10 (SEL), IC21.13 (Q)
unnamed: IC11.3 (Y), IC11.15 (Z), R17.1
unnamed: IC11.9 (SEL), IC23.5 (Q)
unnamed: C6.2, IC10.6, IC11.5 (X), R18.2
unnamed: IC9.2 (R-Y), IC11.4 (Z)
unnamed: IC14.3 (OUT), IC23.11 (Cp)
unnamed: IC14.9 (IN1), IC27.6
unnamed: IC14.10 (IN2), IC32.13 (QA)
unnamed: IC14.8 (OUT), IC23.12 (D)
unnamed: IC14.11 (OUT), IC27.1, IC27.2
unnamed: C40.1, IC15.5 (OSCin), XL2.1
unnamed: IC15.6 (OSCout), R37.1
unnamed: IC15.27 (S0), IC33.1 (A)
unnamed: IC15.26 (S1), IC33.2 (B)
unnamed: IC15.25 (S2), IC31.12, IC33.3 (C)
unnamed: IC15.28 (Z0), R25.1
unnamed: IC15.29 (Z1), R24.1
unnamed: IC15.30 (Z2), R23.1
unnamed: IC15.31 (Z3), R22.1
unnamed: IC15.32 (Z4), R21.1
unnamed: IC15.33 (Z5), R19.1
unnamed: IC15.34 (Z6), R20.1
unnamed: IC15.35 (Z7/~RAS1), R12.1
unnamed: IC15.11 (~CAS), R27.1
unnamed: IC15.12 (~RAS0), R26.1
unnamed: IC15.10 (~WE), R28.1
unnamed: IC20.2 (X0), PL3.1
unnamed: IC20.3 (X1), PL3.2
unnamed: IC20.4 (X2), PL5.1
unnamed: IC20.5 (X3), PL5.2
unnamed: IC20.9 (Z), R55.2
unnamed: C34.1, IC21.15 (RCext), R44.2
unnamed: IC21.4 (~Q), IC23.3 (Cp)
unnamed: IC22.3, R35.2
unnamed: IC22.4, IC22.5, IC27.8
unnamed: IC23.2 (D), IC23.6 (~Q)
unnamed: IC22.12, IC23.9 (Q)
unnamed: IC25.3 (+), R48.1, R50.2, R51.2
unnamed: IC25.2 (_), R45.2, R52.2
unnamed: IC25.5 (+), R53.2, R55.1
unnamed: IC27.5, IC28.6 (Q3), IC28.13 (Cp)
unnamed: IC27.4, IC28.11 (Q0)
unnamed: IC22.8, IC29.1 (Cp)
unnamed: IC22.6, IC29.2 (Mr), IC29.12 (Mr)
unnamed: IC27.13, IC29.5 (Q2)
unnamed: IC29.6 (Q3), IC29.13 (Cp)
unnamed: IC29.11 (Q0), IC30.12
unnamed: IC27.12, IC29.10 (Q1), IC30.13
unnamed: IC27.10, IC29.9 (Q2), IC30.9
unnamed: IC27.9, IC29.8 (Q3), IC30.10
unnamed: IC32.7 (QD), IC32.12 (CKB)
unnamed: IC32.9 (QD), IC32.15 (CKA)
unnamed: IC31.13, IC33.4 (~G2A)
unnamed: IC34.2, R59.2
unnamed: IC34.4, R58.2
unnamed: IC34.6, R57.2
unnamed: IC34.10, R62.2
unnamed: IC34.12, R61.2
unnamed: IC34.15, R60.2
unnamed: IC31.8, IC31.9, IC35.3 (PA1)
unnamed: IC35.12 (PB2), R73.1
unnamed: L1.2, PL5.4
unnamed: L2.2, PL3.4
unnamed: PL4.4, R71.2
unnamed: PL6.9, R8.2, R9.1, Rflying1.1
unnamed: R11.2, RV1.2
unnamed: R32.1, TR1.2 (B)
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

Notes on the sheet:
3us PULSE (APPROX)
DIVIDE VCLK BY 228 TO CREATE LINE PULSE FREQUENCY
DIVIDE BY 50
FLYING RESISOR FITTED TO REDUCE COLOUR BLEED
A7 PULLDOWN PREVENTS WRITE TO SAM DURING RESET
KEYBOARD MATRIX DRIVE
RISING EDGE OF RAS0 CLOCKS MEMORY DATA TO VDG (NOTE: FOR 2 x 16K MACHINES, RAS0 IS ONLY ACTIVE FOR THE LOWER 16K OF MEMORY. THEREFORE IT'S NOT POSSIBLE TO HAVE A DISPLAY IN THE UPPER 16K)
MIX CHROMA & LUMA AMPLIFY / BUFFER
RIGHT FIRE BUTTON
24 LINE DELAY
FS'
R73 PULLUP INDICATES DRAM IS ORGANISED IN 2 x 16K BANKS (PULLDOWN WOULD INDICATE 1 x 64K BANK)
KEYBOARD MATRIX RETURN
SUBSTITUTE ØB FOR ØA DURING BACK PORCH SO THAT CHROMA BURST IS INCLUDED IN PHASE ALTERNATION
22R 11 Places
CRYSTAL / MPU RATE / VSYNC RATE 14.218MHz / 889KHz / 49.97Hz 14.318MHz / 895KHz / 50.32Hz
HSYNC DIVIDED BY 2
STEER VCLK TO VDG OR LINE PULSE CIRCUIT
VCLK PULLED LOW TO PARTIALLY RESET SAM
ENABLE MEMORY DATA TO DATA BUS
DC LEVEL ADJUST
LEFT FIRE BUTTON
HSYNC SIGNAL FOR REST OF SYSTEM
ALTERNATING PHASE
OUTPUT LOW ON COUNT 0-15 LINE PULSE WIDTH = 4.5us
VIDEO SIGNAL TO TV MODULATOR
SELECT LUMA SIGNAL FROM VDG OR EXTRA SYNCS FROM LINE PULSE CIRCUIT

Board: 2 copper layers, 215 parts (0 on the bottom side), 228 nets, no tracks yet.

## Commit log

2023-07-10 add pcb to project
    [Dragon32_MKII.kicad_pcb, Dragon32_MKII.kicad_sch]
2023-07-10 align component positions to board
    [Dragon32_MKII.kicad_pcb, Dragon32_MKII.kicad_sch]
2023-07-12 more layout
    [Dragon32_MKII.kicad_pcb, Dragon32_MKII.kicad_sch]
2023-07-12 position components
    [Dragon32_MKII.kicad_pcb, Dragon32_MKII.kicad_sch]
2023-07-13 initial routing of ground plane
    [Dragon32_MKII.kicad_sch]
2023-07-15 reposition pcb components
    [Dragon32_MKII.kicad_sch]
2023-07-17 use scanned pcb images to locate components
2023-07-17 refine component locations
    [Dragon32_MKII.kicad_sch]
2023-07-17 trace routes
    [Dragon32_MKII.kicad_sch]
2023-07-18 more tracing
    [Dragon32_MKII.kicad_sch]
2023-07-18 complete tracing
    [Dragon32_MKII.kicad_sch]
2023-07-18 finish tracing with relay
    [Dragon32_MKII.kicad_sch]
2023-10-05 fix z1 z2 wiring
    [Dragon32_MKII.kicad_sch]
